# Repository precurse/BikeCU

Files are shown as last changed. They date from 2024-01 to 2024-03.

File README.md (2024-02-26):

# BikeCU

## Background
BikeCU is an open-source project that enhances the functionality of the Schwinn IC4 indoor cycling bike by providing additional data not available on its built-in display. This includes power (watt) data, integer-style RPM, maximum heart rate, and more. Additionally, BikeCU facilitates the seamless transfer of data to a time-series database, such as InfluxDB, with per-second granularity. Users can then choose to export the data in TCX format for archival purposes and upload it to popular data aggregators like Runalyze or Strava.

While BikeCU has been primarily designed for the Schwinn IC4, it should be versatile enough to work with any BLE-enabled bike.

## Features
- *Power Output Display*: View real-time power output data during your cycling sessions.
- *Improved Cadence Display*: Cadence is shown as an easily readable integer.
- *Auto-connecting to Bike and HR Monitor*: BikeCU ensures a hassle-free connection to your bike and heart rate monitor.
- *HR Monitor Battery Monitoring*: Keep track of your heart rate monitor's battery status.
- *Metric Shuttling to InfluxDB*: Stream data to InfluxDB in per-second granularity for detailed analysis.
- *Export to TCX format*: Choose to export your data in TCX format for archival purposes.
- *Integration with Runalyze and Strava*: Directly export data to popular data aggregators for a comprehensive overview of your cycling performance.
- *Over-the-Air Updating*: Update your BikeCU firmware wirelessly.
- *Data Ownership and Control*: BikeCU prioritizes user data privacy, allowing you to be the owner of your fitness data. You have full control over how and where your data is stored and shared.

## Hardware Required
- ESP32-C3 ([source](https://www.aliexpress.com/item/1005004490215444.html)) [board details](https://wiki.luatos.org/chips/esp32c3/board.html)
- TFT ST7735-based Display (1.77" [source](https://www.aliexpress.com/item/1005003797803015.html))
- USB-A to USB-C cable
- M2 machine screws for case install
- Protoboard (3cm * 7cm)
- Hot-glue gun

While BikeCU has been designed for the ESP32-C3, other ESP32 variants with BLE support should also work. Note that the ESP32-S2 is not compatible.

## Setup

### Project Wiring

| ESP32 | LCD Display |
|---|---|
| GND | GND |
| 3.3V | VCC |
| IO02 | SCK |
| IO03 | SDA |
| IO10 | RES |
| IO06 | RS |
| IO07 | CS |
| IO05 | LEDA |

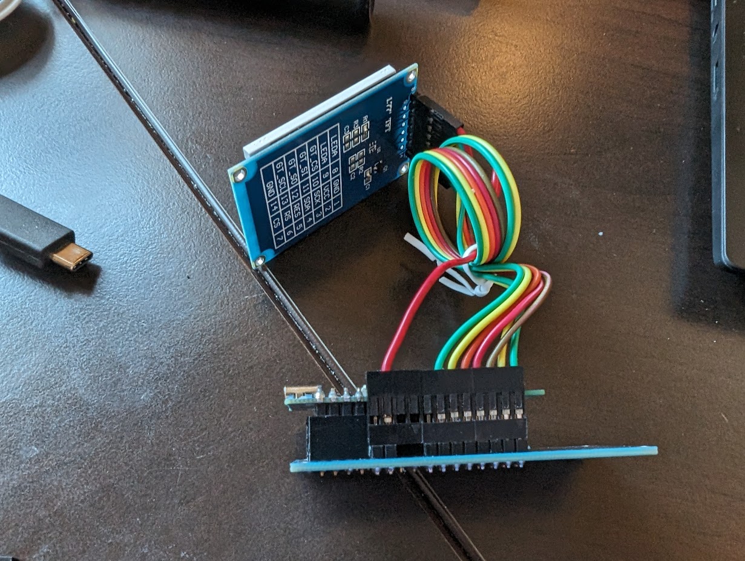
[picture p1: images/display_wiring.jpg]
Display Wiring


### Compiling
```sh
git clone https://github.com/precurse/bikecu
pip3 install platformio
pio run
```

### Flashing Firmware
```sh
pio run -v -t upload --upload-port /dev/ttyACM0
```

### Soldering Protoboard
_In progress_

### 3D Printing Case
Print with no supports like so:
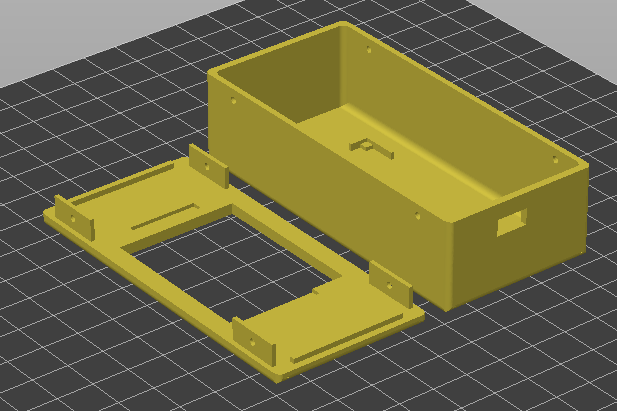
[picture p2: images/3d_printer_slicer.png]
slicer


Place ESP32 onto protoboard and into the case:
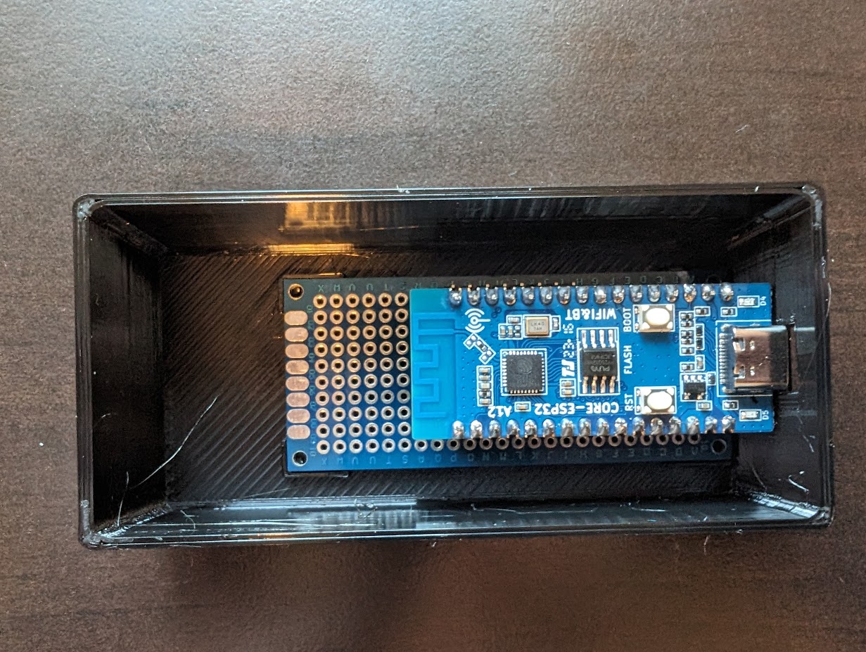
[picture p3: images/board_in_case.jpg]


### Final Assembly
- Insert display onto the lid and use hot glue to keep in place
- Place lid onto the case
- Screw four M2 machine screws into the four outside holes
- Final assembly will look like:
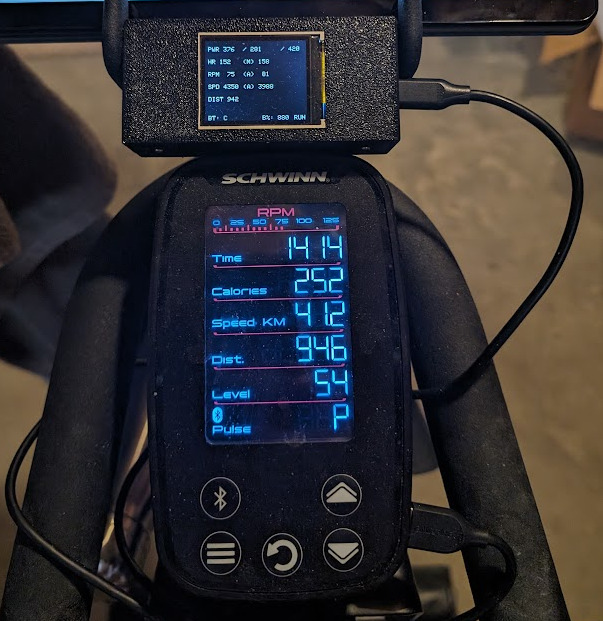
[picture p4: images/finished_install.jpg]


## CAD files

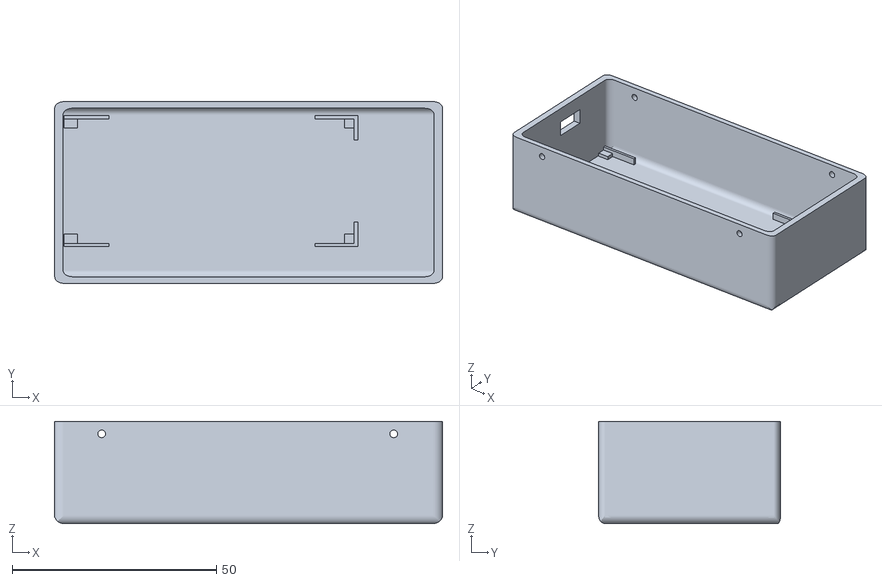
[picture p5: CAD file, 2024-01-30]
case/bikecu_base.stl
95.0 x 44.5 x 25.0

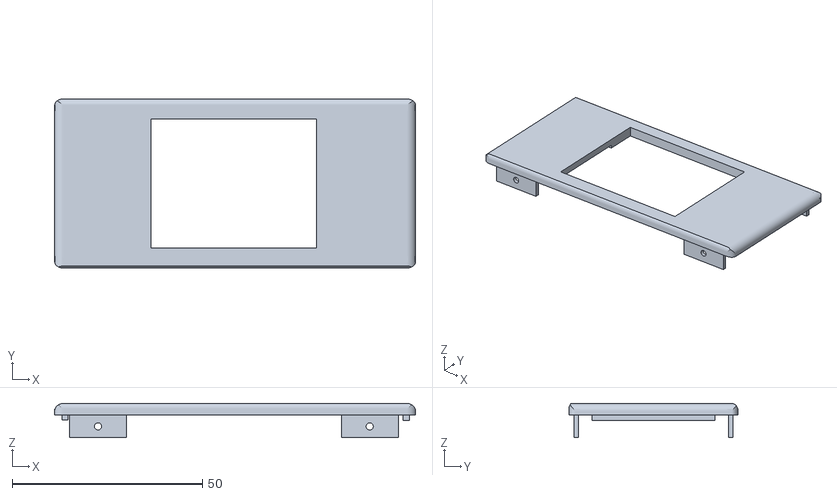
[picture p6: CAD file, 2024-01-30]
case/bikecu_lid.stl
95.0 x 44.5 x 8.99

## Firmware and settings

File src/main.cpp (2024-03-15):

#include "config.h"
#include "session.h"
#include "utils.h"
#include "bluetooth.h"
#include "display.h"
#include "influxdb.h"
#include "wifi.h"

#include <ArduinoOTA.h>
#include <NTPClient.h>
#include <time.h>
#include <WiFi.h>
#include <freertos/FreeRTOS.h>
#include <freertos/task.h>

// Globals
QueueHandle_t dataQueue;
QueueHandle_t serialQ;
SemaphoreHandle_t bikeDataMutex;
LiveBikeData bikeData;
CycleSession cycleSession;

void setup()
{
  Serial.begin(115200);
  #ifdef DEBUG
    delay(1000);
  #endif

  // Initialize data types needed
  dataQueue = xQueueCreate(20, sizeof(struct CycleSession));
  serialQ = xQueueCreate(20, sizeof(String) * 100);
  bikeDataMutex = xSemaphoreCreateMutex();
  initializeSession(&bikeData, &cycleSession);

  Serial.println("[SETUP] Creating tasks...");
  // 768 bytes is required for task overhead
  #ifdef FEATURE_WIFI
    xTaskCreate(taskKeepWifiAlive, "WIFI_HANDLE", 2300, NULL, 1, NULL);
  #endif

  xTaskCreate(taskBLE, "BLE_HANDLE", 4000, NULL, 1, NULL);
  xTaskCreate(taskSession, "SESSION_HANDLE", 1000, NULL, 1, NULL);
  
  #ifdef FEATURE_DISPLAY
    xTaskCreate(taskDisplay, "DISPLAY_HANDLE", 1000, NULL, 2, NULL);
  #endif

  // xTaskCreate(taskSerialPrint, "SERIAL_HANDLE", 1000, NULL, 1, NULL);
  #ifdef FEATURE_INFLUX
    xTaskCreate(taskInflux, "INFLUX_HANDLE", 2000, NULL, 1, NULL);
  #endif

  #ifdef FEATURE_OTA
    xTaskCreate(taskOta, "OTA_HANDLE", 1000, NULL, 2, NULL);
  #endif

  // Remove Arduino setup and loop tasks
  vTaskDelete(NULL);
}

void loop()
{
}

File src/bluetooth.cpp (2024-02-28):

#include "config.h"
#include "constants.h"
#include <NimBLEUUID.h>
#include <NimBLEAddress.h>
#include <NimBLEClient.h>
#include "NimBLEDevice.h"

time_t lastBtConnectTime = 0;
StateBle stateBleBike;
StateBle stateBleHr;

static NimBLEAddress *pBikeAddress;
static NimBLEAddress *pHrAddress;
NimBLEClient *pBikeClient;
NimBLEClient *pHrClient;

// static BLERemoteCharacteristic* bikeCharacteristic;
static NimBLERemoteDescriptor *bikeDescriptor;

void scanEndedCB(NimBLEScanResults results)
{
  Serial.println("Scan Ended");
}

void bikeNotifyCallback(BLERemoteCharacteristic *pBLERemoteCharacteristic,
                        uint8_t *pData,
                        size_t length,
                        bool isNotify)
{
  lastBtConnectTime = getUnixTimestamp();

  // TODO: Make more dynamic. Check header flags

  if (length >= 9)
  {
    // Extracting values directly by casting bytes
    if (xSemaphoreTake(bikeDataMutex, portMAX_DELAY) == pdTRUE)
    {
      bikeData.header = *((uint16_t *)&pData[0]);
      bikeData.speed = *((uint16_t *)&pData[2]);
      bikeData.cadence = *((uint16_t *)&pData[4]);
      bikeData.power = *((uint16_t *)&pData[6]);
      uint8_t hrLive = pData[8];
      // Only use Bike HR data if present
      if (hrLive > 0)
      {
        bikeData.hr = hrLive; // Fourth unsigned char (1 byte)
      }

      // if session is running, track accumulators for averages
      if (cycleSession.sessionState == Running)
      {
        bikeData.speedAccum += bikeData.speed;
        bikeData.cadenceAccum += bikeData.cadence;
        bikeData.powerAccumu += bikeData.power;
        bikeData.metricCnt++;

        // HR may not be present
        if (hrLive > 0)
        {
          bikeData.hrAccum += bikeData.hr;
          bikeData.hrCnt++;
        }
      }
      // Done with updating data
      xSemaphoreGive(bikeDataMutex);
    }
  }
}

bool bleCharNotify(BLEClient *pClient, const NimBLEUUID bleSvcUUID, const NimBLEUUID bleCharUUID, notify_callback bleNotifyCallback = nullptr)
{
  BLERemoteService *pRemoteService = pClient->getService(bleSvcUUID);
  Serial.println("[BLECharNotify] Begin");
  if (pRemoteService == nullptr)
  {
    Serial.print("[BLE] Failed to find service UUID");
    Serial.println(bleSvcUUID.toString().c_str());
    return false;
  }
  Serial.println("[BLECharNotify] found serviceUUID");

  BLERemoteCharacteristic *bleChar = pRemoteService->getCharacteristic(bleCharUUID);

  if (bleChar == nullptr)
  {
    Serial.print("[BLE] Failed to find characteristic UUID");
    Serial.println(bleCharUUID.toString().c_str());
    return false;
  }
  Serial.println("[BLECharNotify] found charUUID");

  if (bleChar->canNotify())
  {
    if (!bleChar->subscribe(true, bleNotifyCallback))
    {
      return false;
    }
  }
  return true;
}

void hrNotifyCallback(BLERemoteCharacteristic *pBLERemoteCharacteristic,
                      uint8_t *pData,
                      size_t length,
                      bool isNotify)
{
  // Serial.print("[BLEData] HR length: ");
  // Serial.println(length);
  // HR has an 8-bit header
  // https://github.com/oesmith/gatt-xml/blob/master/org.bluetooth.characteristic.heart_rate_measurement.xml
  if (length >= 2)
  {
    // TODO: We should really check the header whether HR is uint8 or uint16
    uint8_t header = pData[0];

    if (xSemaphoreTake(bikeDataMutex, portMAX_DELAY) == pdTRUE)
    {
      uint8_t hrLive = pData[1];

      bikeData.hr = hrLive;
      if (cycleSession.sessionState == Running)
      {
        bikeData.hrAccum += hrLive;
        bikeData.hrCnt++;
      }
      // Done with bike data
      xSemaphoreGive(bikeDataMutex);
    }
  }
}

bool connectToBike(BLEAddress pAddress)
{
  pBikeClient = BLEDevice::createClient();
  Serial.println("[BLE] Trying to connect to bike");
  pBikeClient->connect(pAddress, true);
  stateBleBike = Connected;
  Serial.println("[BLE]  - Connected to server");

  // Subscribe to Fitness Machine indoor bike data
  if (!bleCharNotify(pBikeClient, fmServiceUUID, indoorBikeDataCharUUID, bikeNotifyCallback))
  {
    Serial.println("[BLE]  - Subscribed to Fitness Machine");
    if (pBikeClient != nullptr)
    {
      Serial.println("[BLE]  - Fitness machine had null pointer");
      NimBLEDevice::deleteClient(pBikeClient);
    }
    return false;
  }
  return true;
}

bool bleCharRead(BLEClient *pClient, const NimBLEUUID bleSvcUUID, const NimBLEUUID bleCharUUID, uint8_t *metric)
{
  BLERemoteService *pRemoteService = pClient->getService(bleSvcUUID);

  if (pRemoteService == nullptr)
  {
    Serial.print("[BLE] Failed to find service UUID");
    Serial.println(bleSvcUUID.toString().c_str());
    return false;
  }

  BLERemoteCharacteristic *bleChar = pRemoteService->getCharacteristic(bleCharUUID);

  if (bleChar == nullptr)
  {
    Serial.print("[BLE] Failed to find characteristic UUID");
    Serial.println(bleCharUUID.toString().c_str());
    return false;
  }

  // Ensure we can read characteristic
  if (bleChar->canRead())
  {
    *metric = bleChar->readValue<uint8_t>();
  }
  return true;
}

void hrBattNotifyCallback(BLERemoteCharacteristic *pBLERemoteCharacteristic,
                          uint8_t *pData,
                          size_t length,
                          bool isNotify)
{
  Serial.print("[BLEData] HR Batt length: ");
  Serial.println(length);
  // org.bluetooth.unit.percentage is 8-bit
  // https://github.com/sputnikdev/bluetooth-gatt-parser/blob/master/src/main/resources/gatt/characteristic/org.bluetooth.characteristic.battery_level.xml
  if (length >= 1)
  {
    // uint8_t header = pData[0];
    if (xSemaphoreTake(bikeDataMutex, portMAX_DELAY) == pdTRUE)
    {
      bikeData.hrBatt = pData[0];
      // Done with updating data
      xSemaphoreGive(bikeDataMutex);
    }
  }
}

bool connectToHr(BLEAddress pAddress)
{
  pHrClient = BLEDevice::createClient();
  pHrClient->connect(pAddress, false);
  stateBleHr = Connected;
  Serial.println("[BLE] Connected to HR device");

  // Subscribe to HR metricsew
  if (!bleCharNotify(pHrClient, hrServiceUUID, hrCharUUID, hrNotifyCallback))
  {
    if (pHrClient != nullptr)
    {
      NimBLEDevice::deleteClient(pHrClient);
    }
    return false;
  }

  // Read HR battery at start
  bleCharRead(pHrClient, hrBattServiceUUID, hrBattCharUUID, &bikeData.hrBatt);

  // HR battery updates will then be pushed
  bleCharNotify(pHrClient, hrBattServiceUUID, hrBattCharUUID, hrBattNotifyCallback);

  return true;
}
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
